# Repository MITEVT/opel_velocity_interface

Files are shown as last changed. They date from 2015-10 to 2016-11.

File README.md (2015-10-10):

# Opel GT Driver Interface Module

MIT EVT's Opel GT Project Driver Interface Module. Acts as an inteface between the user and the electrical system for controlling power distribution and auxiliary peripherals.
	
## Target
NXP LPC11C14 Cortex-M0 Microcontroller

## Description
Takes user input in the form of key switches, level toggles, and button presses to activate main power distribution system and control auxilairy peripherals such as lights.

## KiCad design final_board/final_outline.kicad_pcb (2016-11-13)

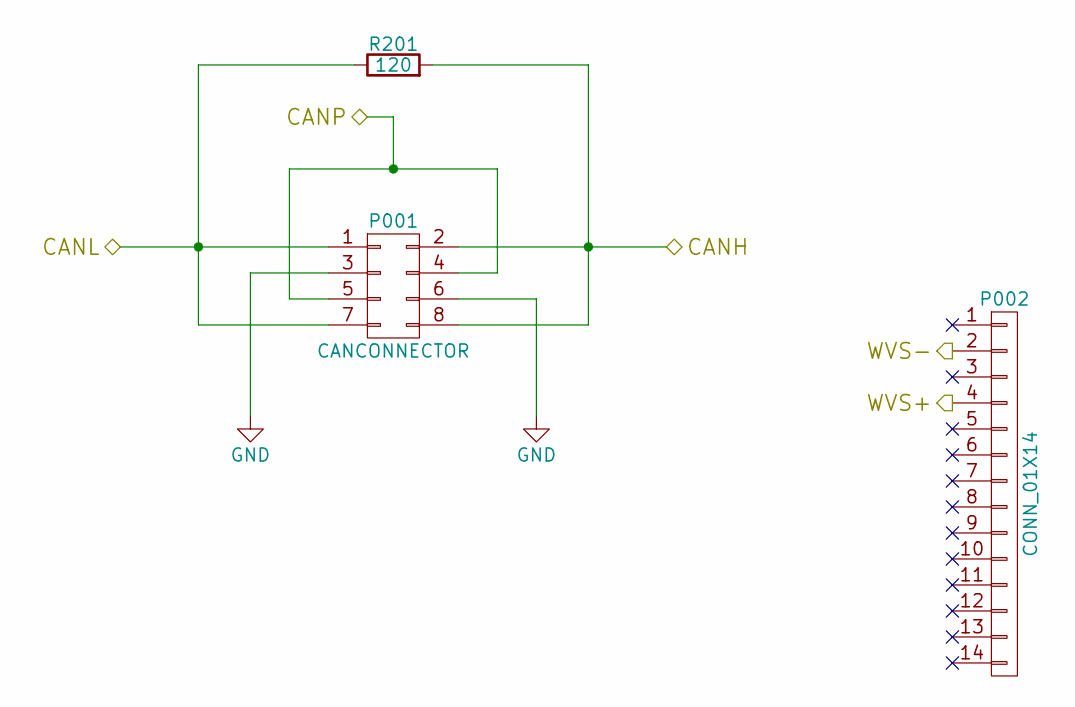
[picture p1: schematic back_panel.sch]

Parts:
P001: CANCONNECTOR; 776280-1
P002: CONN_01X14; 776267-1
R201: 120; R_0603_HandSoldering

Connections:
+12V: P001.4, P001.5; also elsewhere on the board
/BACK_PANEL/CANH: P001.2, P001.8, R201.2; also elsewhere on the board
/BACK_PANEL/CANL: P001.1, P001.7, R201.1; also elsewhere on the board
/BACK_PANEL/WVS+: P002.4; also elsewhere on the board
/BACK_PANEL/WVS-: P002.2; also elsewhere on the board
GND: P001.3, P001.6; also elsewhere on the board

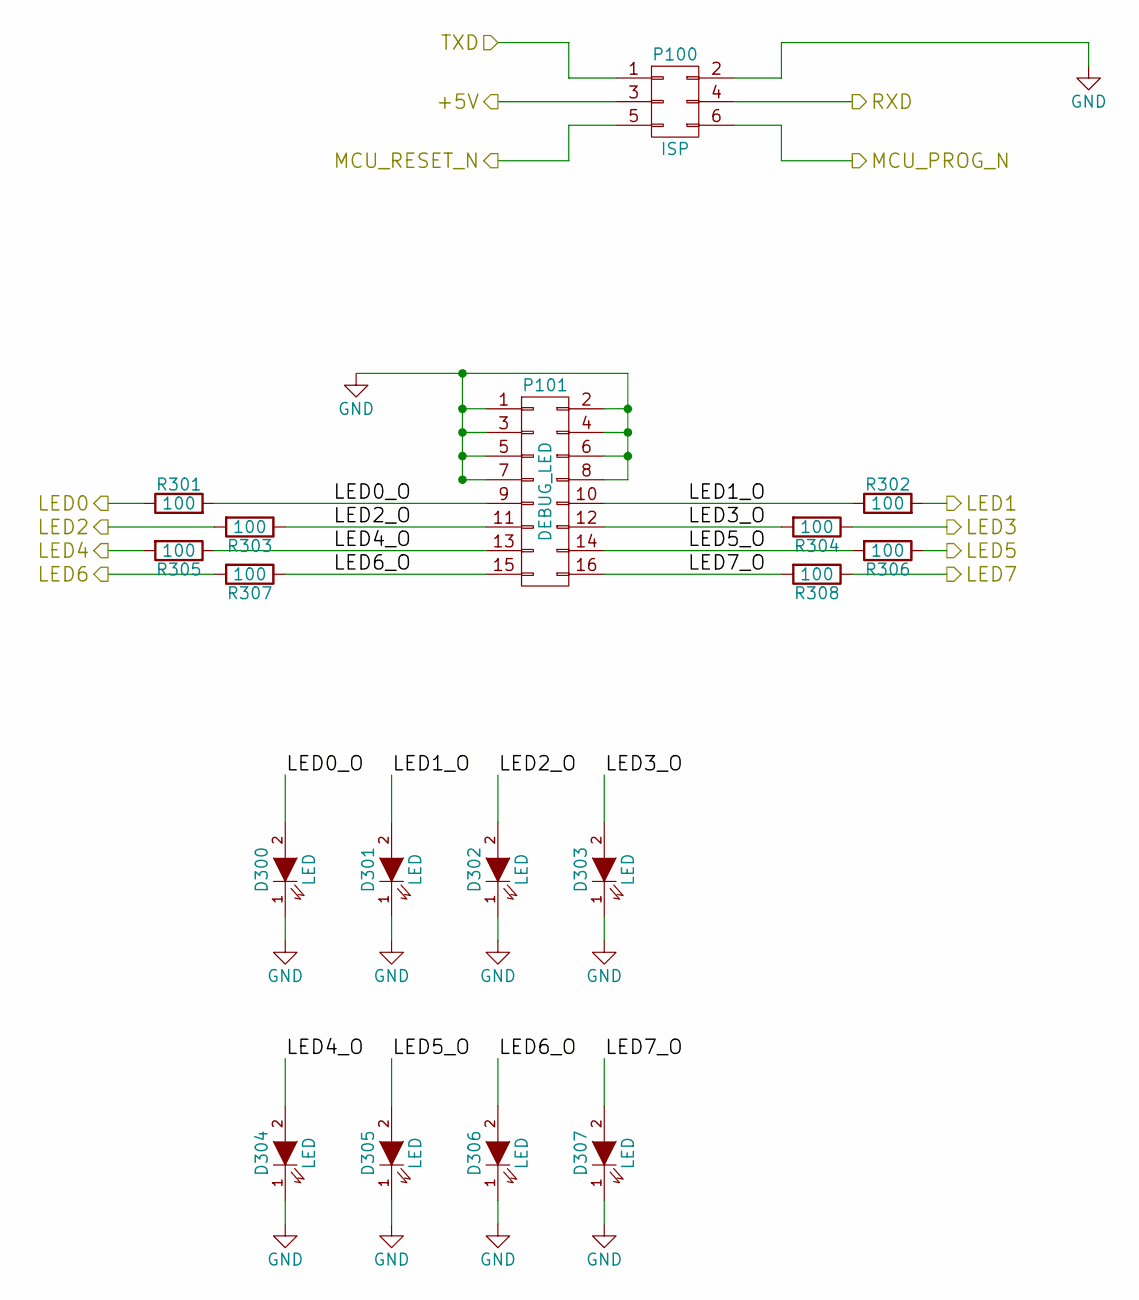
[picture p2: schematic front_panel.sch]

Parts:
D300, D301, D302, D303, D304, D305, D306, D307: LED; LED_0805
P100: ISP; Molex_Microfit3_Header_02x03_Angled_43045-060x
P101: DEBUG_LED; Molex_Microfit3_Header_02x08_Angled_43045-160x
R301, R302, R303, R304, R305, R306, R307, R308: 100; R_0603_HandSoldering

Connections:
+5V: P100.3; also elsewhere on the board
/FRONT_PANEL/LED0: R301.1; also elsewhere on the board
/FRONT_PANEL/LED0_O: D300.2 (A), P101.9, R301.2
/FRONT_PANEL/LED1: R302.2; also elsewhere on the board
/FRONT_PANEL/LED1_O: D301.2 (A), P101.10, R302.1
/FRONT_PANEL/LED2: R303.2; also elsewhere on the board
/FRONT_PANEL/LED2_O: D302.2 (A), P101.11, R303.1
/FRONT_PANEL/LED3: R304.1; also elsewhere on the board
/FRONT_PANEL/LED3_O: D303.2 (A), P101.12, R304.2
/FRONT_PANEL/LED4: R305.2; also elsewhere on the board
/FRONT_PANEL/LED4_O: D304.2 (A), P101.13, R305.1
/FRONT_PANEL/LED5: R306.1; also elsewhere on the board
/FRONT_PANEL/LED5_O: D305.2 (A), P101.14, R306.2
/FRONT_PANEL/LED6: R307.2; also elsewhere on the board
/FRONT_PANEL/LED6_O: D306.2 (A), P101.15, R307.1
/FRONT_PANEL/LED7: R308.1; also elsewhere on the board
/FRONT_PANEL/LED7_O: D307.2 (A), P101.16, R308.2
/FRONT_PANEL/MCU_PROG_N: P100.6; also elsewhere on the board
/FRONT_PANEL/MCU_RESET_N: P100.5; also elsewhere on the board
/FRONT_PANEL/RXD: P100.4; also elsewhere on the board
/FRONT_PANEL/TXD: P100.1; also elsewhere on the board
GND: D300.1 (K), D301.1 (K), D302.1 (K), D303.1 (K), D304.1 (K), D305.1 (K), D306.1 (K), D307.1 (K), P100.2, P101.1, P101.2, P101.3, P101.4, P101.5, P101.6, P101.7, P101.8; also elsewhere on the board

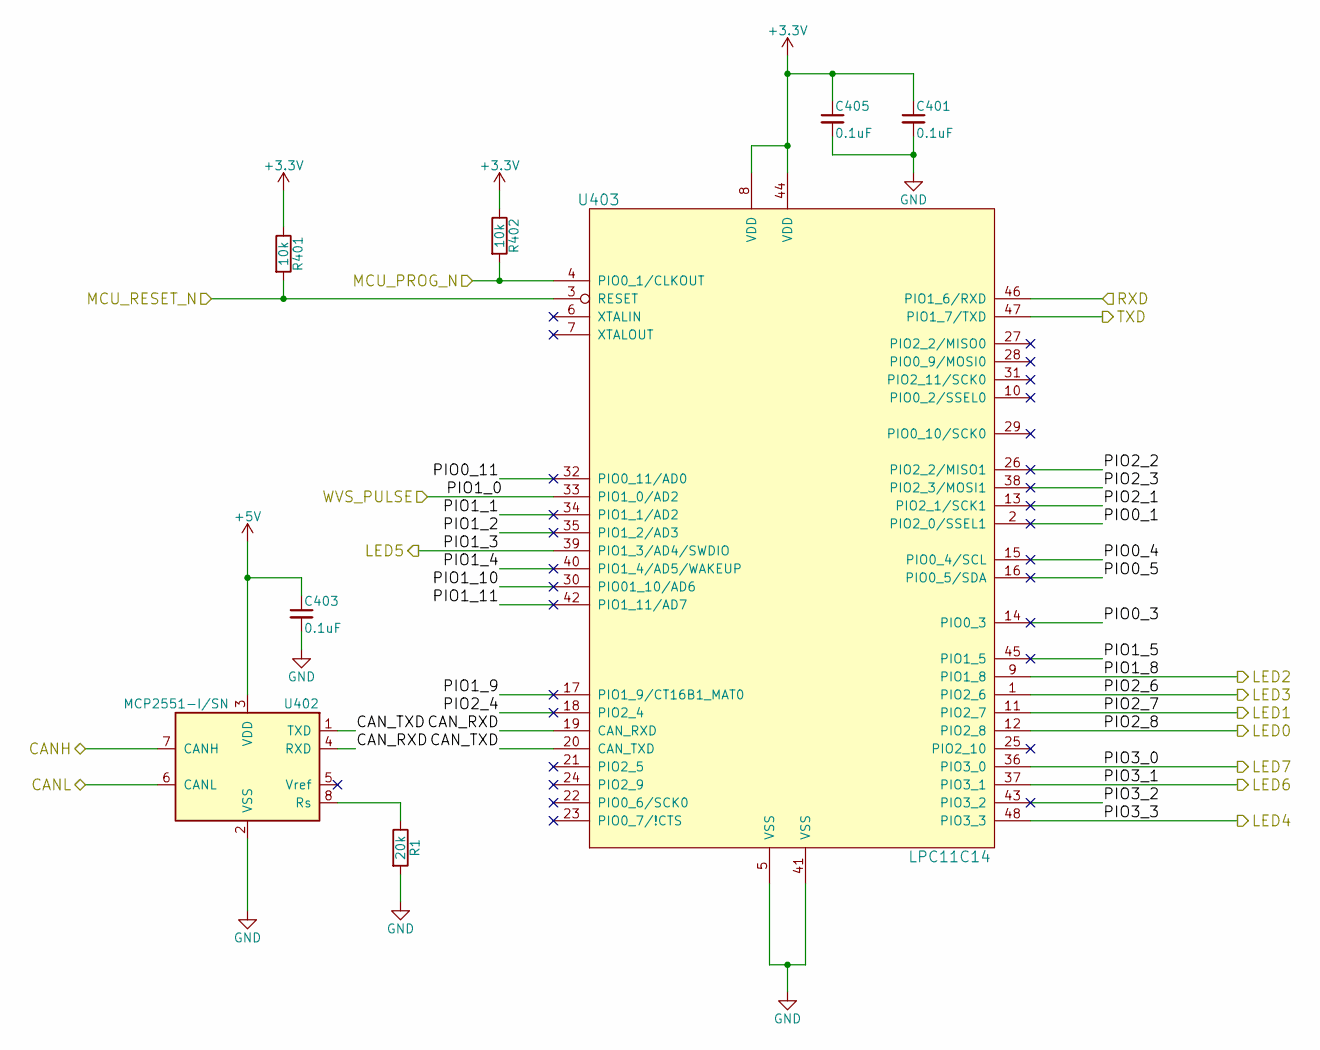
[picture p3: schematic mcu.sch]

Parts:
C401, C403, C405: 0.1uF; C_0603_HandSoldering
R1: 20k; C_0603_HandSoldering
R401, R402: 10k; R_0603_HandSoldering
U402: MCP2551-I/SN; SOIC-8_3.9x4.9mm_Pitch1.27mm
U403: LPC11C14; LQFP-48_7x7mm_Pitch0.5mm

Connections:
+3V3: C401.1, C405.1, R401.1, R402.1, U403.8 (VDD), U403.44 (VDD); also elsewhere on the board
+5V: C403.1, U402.3 (VDD); also elsewhere on the board
/BACK_PANEL/CANH: U402.7 (CANH); also elsewhere on the board
/BACK_PANEL/CANL: U402.6 (CANL); also elsewhere on the board
/FRONT_PANEL/LED0: U403.12 (PIO2_8); also elsewhere on the board
/FRONT_PANEL/LED1: U403.11 (PIO2_7); also elsewhere on the board
/FRONT_PANEL/LED2: U403.9 (PIO1_8); also elsewhere on the board
/FRONT_PANEL/LED3: U403.1 (PIO2_6); also elsewhere on the board
/FRONT_PANEL/LED4: U403.48 (PIO3_3); also elsewhere on the board
/FRONT_PANEL/LED5: U403.39 (PIO1_3/AD4/SWDIO); also elsewhere on the board
/FRONT_PANEL/LED6: U403.37 (PIO3_1); also elsewhere on the board
/FRONT_PANEL/LED7: U403.36 (PIO3_0); also elsewhere on the board
/FRONT_PANEL/MCU_PROG_N: R402.2, U403.4 (PIO0_1/CLKOUT); also elsewhere on the board
/FRONT_PANEL/MCU_RESET_N: R401.2, U403.3 (RESET); also elsewhere on the board
/FRONT_PANEL/RXD: U403.46 (PIO1_6/RXD); also elsewhere on the board
/FRONT_PANEL/TXD: U403.47 (PIO1_7/TXD); also elsewhere on the board
/Micro_Controller/CAN_RXD: U402.4 (RXD), U403.19 (CAN_RXD)
/Micro_Controller/CAN_TXD: U402.1 (TXD), U403.20 (CAN_TXD)
/Micro_Controller/PIO0_1: U403.2 (PIO2_0/SSEL1)
/Micro_Controller/PIO0_3: U403.14 (PIO0_3)
/Micro_Controller/PIO0_4: U403.15 (PIO0_4/SCL)
/Micro_Controller/PIO0_5: U403.16 (PIO0_5/SDA)
/Micro_Controller/PIO0_11: U403.32 (PIO0_11/AD0)
/Micro_Controller/PIO1_1: U403.34 (PIO1_1/AD2)
/Micro_Controller/PIO1_2: U403.35 (PIO1_2/AD3)
/Micro_Controller/PIO1_4: U403.40 (PIO1_4/AD5/WAKEUP)
/Micro_Controller/PIO1_5: U403.45 (PIO1_5)
/Micro_Controller/PIO1_9: U403.17 (PIO1_9/CT16B1_MAT0)
/Micro_Controller/PIO1_10: U403.30 (PIO01_10/AD6)
/Micro_Controller/PIO1_11: U403.42 (PIO1_11/AD7)
/Micro_Controller/PIO2_1: U403.13 (PIO2_1/SCK1)
/Micro_Controller/PIO2_2: U403.26 (PIO2_2/MISO1)
/Micro_Controller/PIO2_3: U403.38 (PIO2_3/MOSI1)
/Micro_Controller/PIO2_4: U403.18 (PIO2_4)
/Micro_Controller/PIO3_2: U403.43 (PIO3_2)
/Micro_Controller/WVS_PULSE: U403.33 (PIO1_0/AD2); also elsewhere on the board
GND: C401.2, C403.2, C405.2, R1.2, U402.2 (VSS), U403.5 (VSS), U403.41 (VSS); also elsewhere on the board
unnamed: R1.1, U402.8 (Rs)

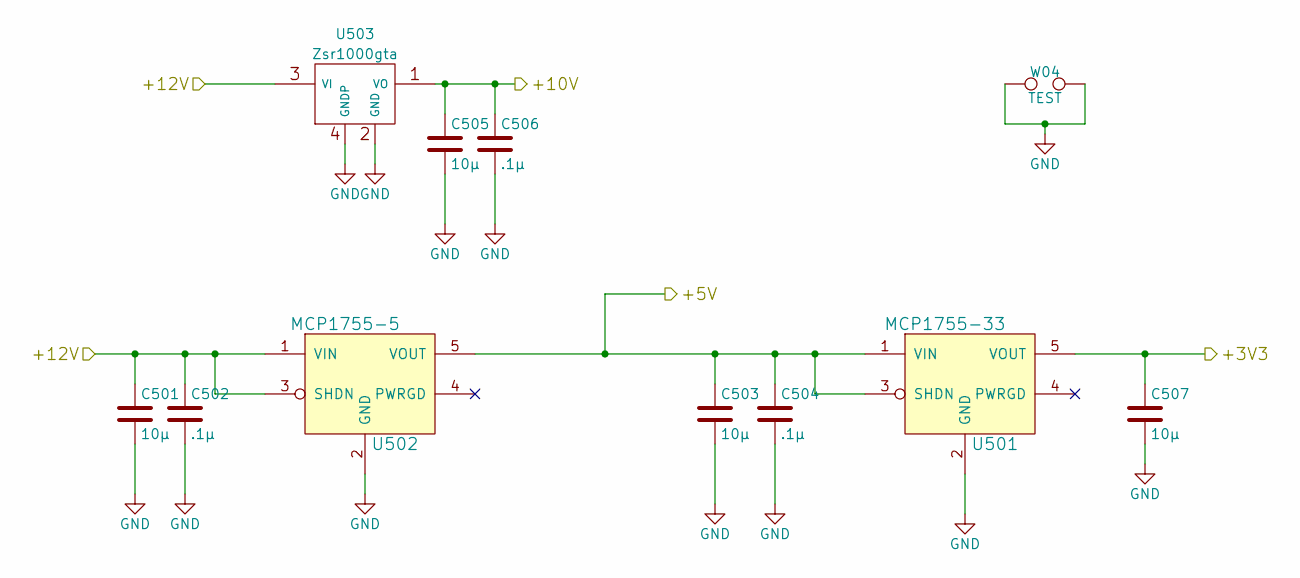
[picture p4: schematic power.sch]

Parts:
C501, C503, C505, C507: 10μ; C_0805_HandSoldering
C502, C504, C506: .1μ; C_0603_HandSoldering
U501: MCP1755-33; SOT-23-5
U502: MCP1755-5; SOT-23-5
U503: Zsr1000gta; SOT-223
W04: TEST; Test_Point_2Pads

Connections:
+3V3: C507.1, U501.5 (VOUT); also elsewhere on the board
+5V: C503.1, C504.1, U501.1 (VIN), U501.3 (SHDN), U502.5 (VOUT); also elsewhere on the board
+12V: C501.1, C502.1, U502.1 (VIN), U502.3 (SHDN), U503.3 (VI); also elsewhere on the board
GND: C501.2, C502.2, C503.2, C504.2, C505.2, C506.2, C507.2, U501.2 (GND), U502.2 (GND), U503.2 (GND), U503.4 (GNDP), W04.1, W04.2; also elsewhere on the board
VCC: C505.1, C506.1, U503.1 (VO); also elsewhere on the board

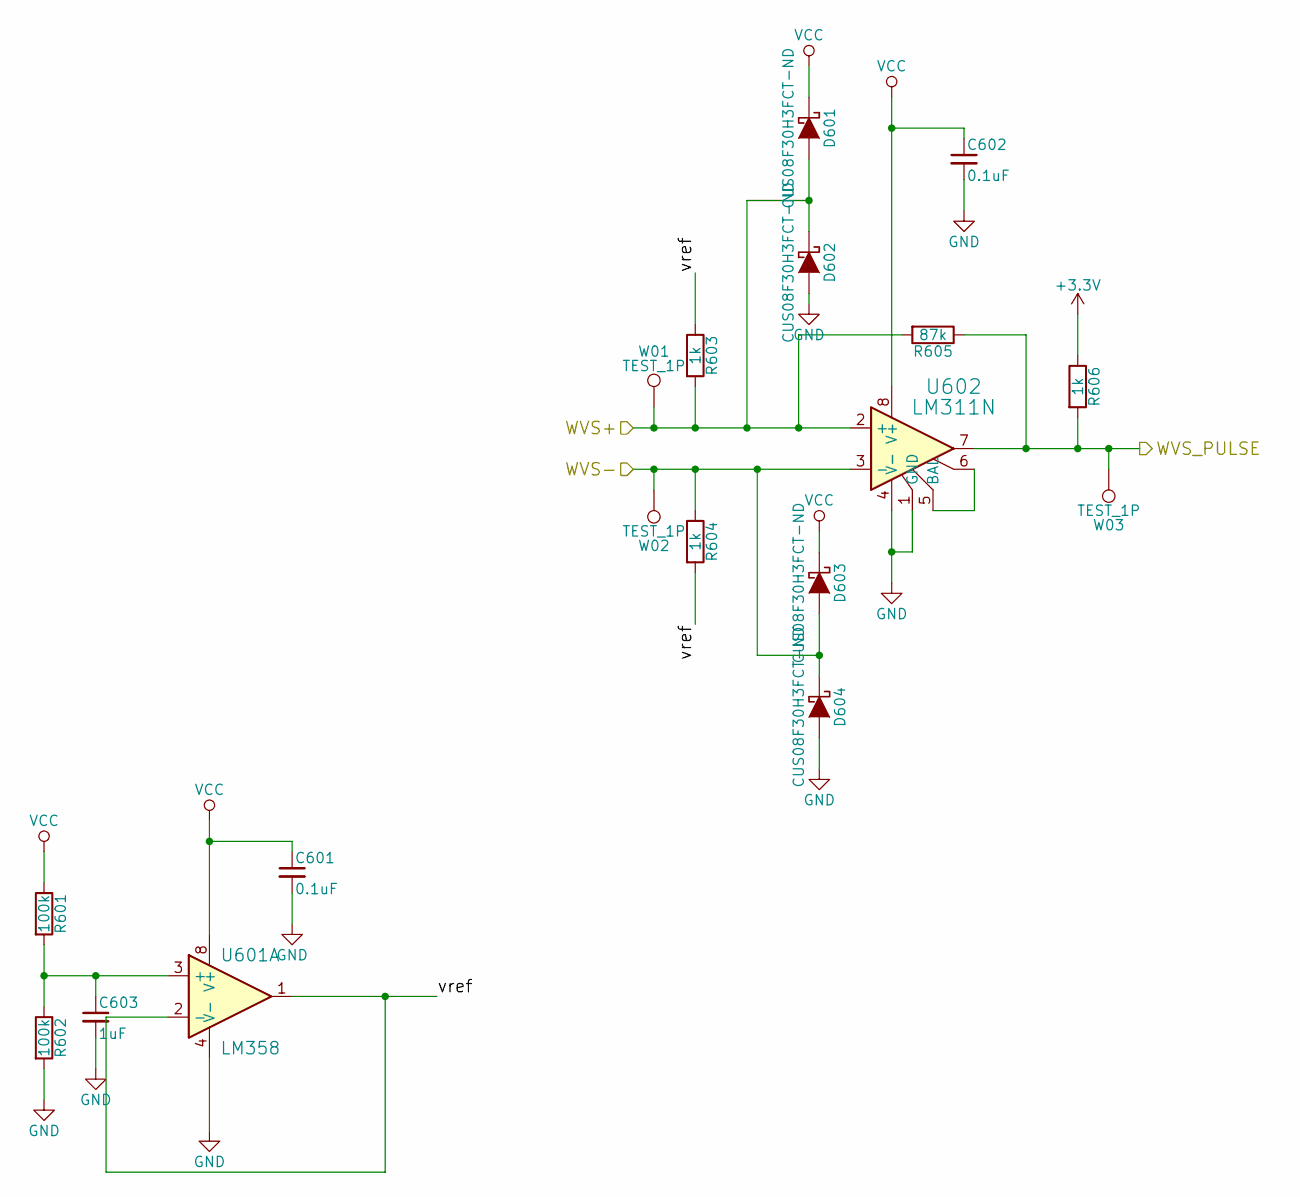
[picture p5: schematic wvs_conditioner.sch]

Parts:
C601, C602: 0.1uF; C_0603_HandSoldering
C603: 1uF; C_0603_HandSoldering
D601, D602, D603, D604: CUS08F30H3FCT-ND; SOD-323
R601, R602: 100k; R_0603_HandSoldering
R603, R604, R606: 1k; R_0603_HandSoldering
R605: 87k; R_0603_HandSoldering
U601: LM358; SOIC-8_3.9x4.9mm_Pitch1.27mm
U602: LM311N; SOIC-8_3.9x4.9mm_Pitch1.27mm
W01, W02, W03: TEST_1P; smd_test_pad

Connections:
+3V3: R606.1; also elsewhere on the board
/BACK_PANEL/WVS+: D601.2 (A), D602.1 (K), R603.2, R605.2, U602.2 (+), W01.1; also elsewhere on the board
/BACK_PANEL/WVS-: D603.2 (A), D604.1 (K), R604.1, U602.3 (-), W02.1; also elsewhere on the board
/Micro_Controller/WVS_PULSE: R605.1, R606.2, U602.7, W03.1; also elsewhere on the board
/WVS_Conditioner/vref: R603.1, R604.2, U601.1, U601.2 (-)
GND: C601.2, C602.2, C603.2, D602.2 (A), D604.2 (A), R602.2, U601.4 (V-), U602.1 (GND), U602.4 (V-); also elsewhere on the board
unnamed: C603.1, R601.2, R602.1, U601.3 (+)
unnamed: U602.5 (BAL), U602.6
VCC: C601.1, C602.1, D601.1 (K), D603.1 (K), R601.1, U601.8 (V+), U602.8 (V+); also elsewhere on the board

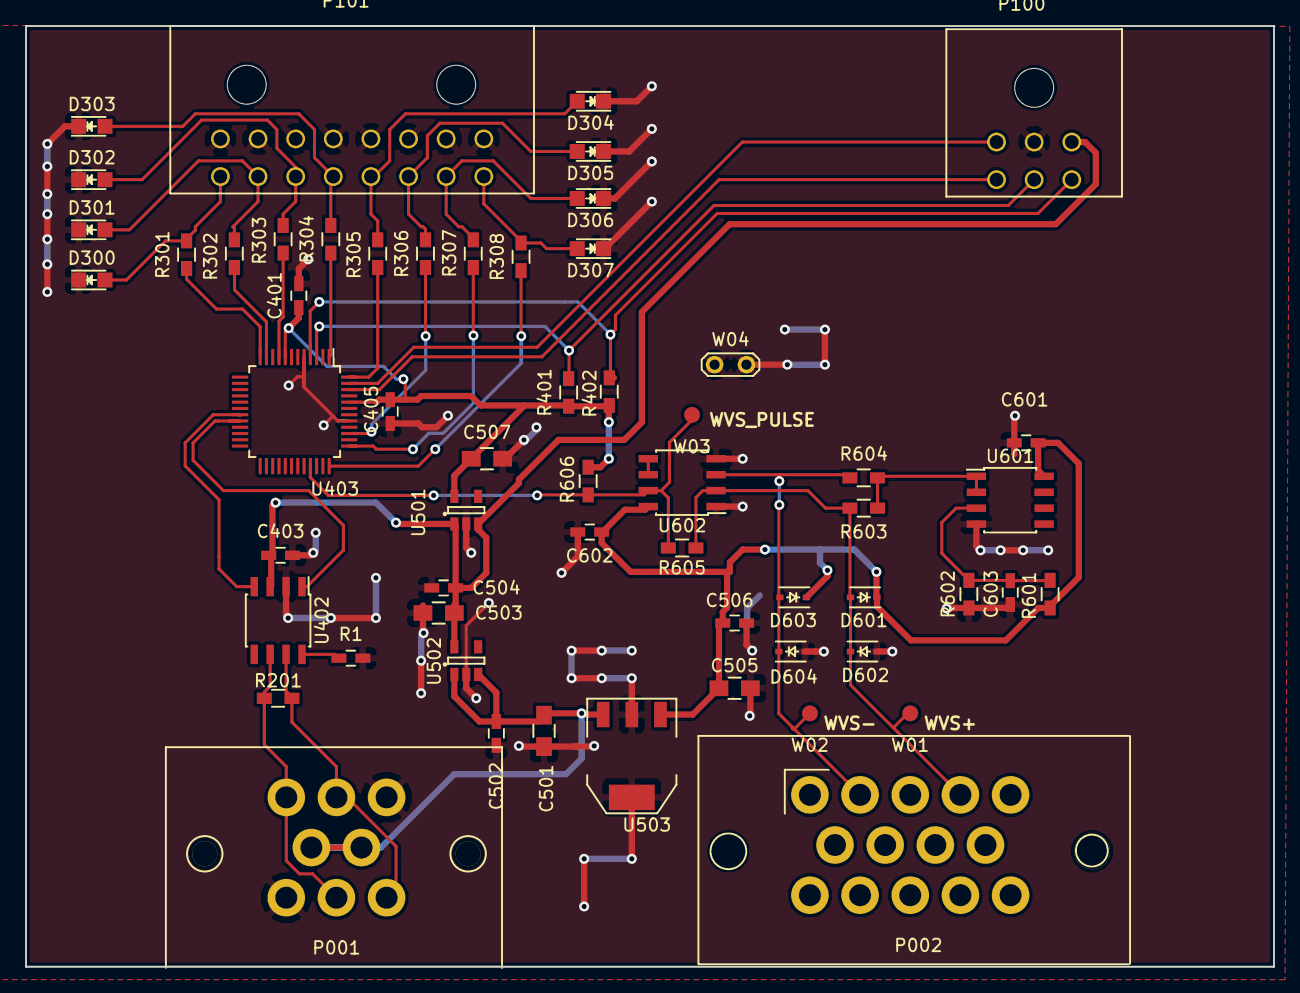
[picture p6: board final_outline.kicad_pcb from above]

Board: 2 copper layers, 99.5 x 75.0 mm, 58 parts (0 on the bottom side), 36 nets.

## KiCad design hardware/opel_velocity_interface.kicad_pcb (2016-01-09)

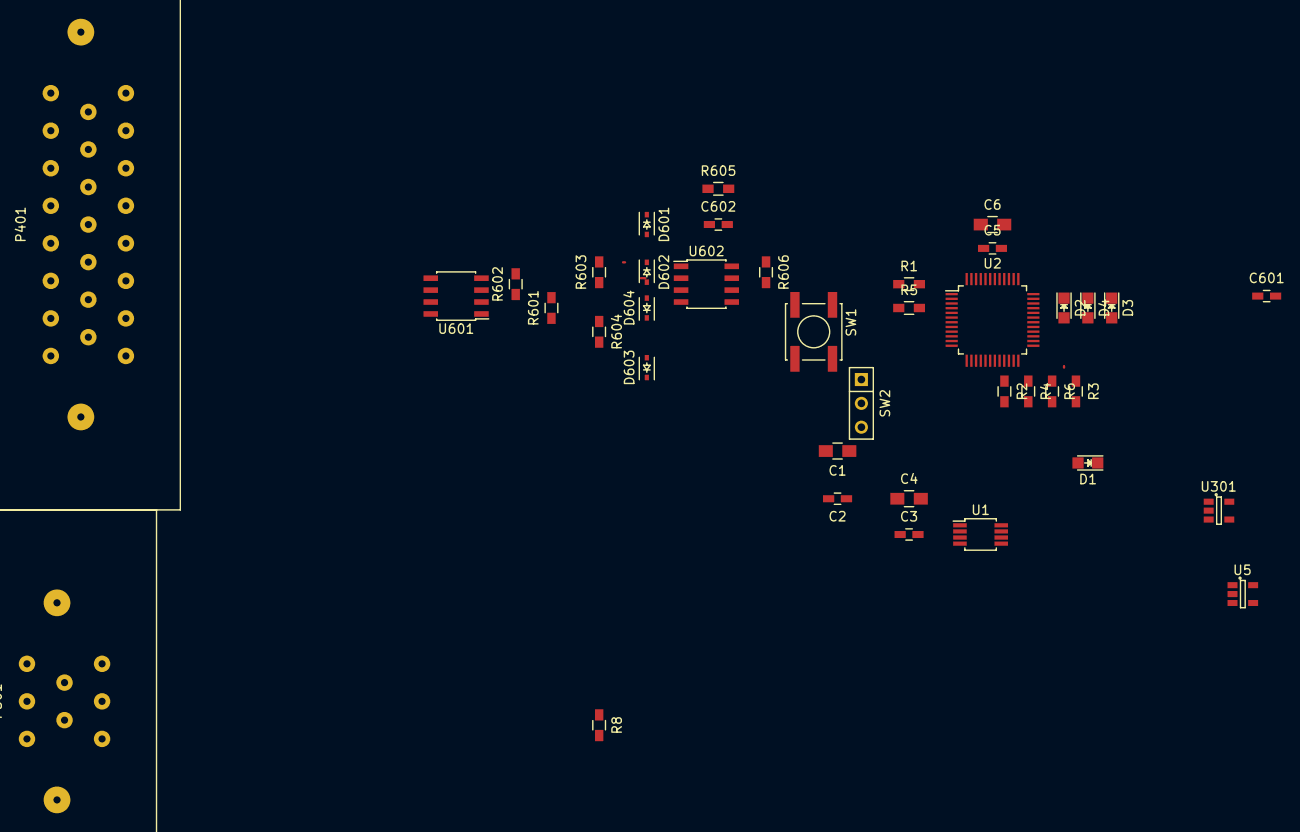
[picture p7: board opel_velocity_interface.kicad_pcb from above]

Board: 2 copper layers, 39 parts (0 on the bottom side), 25 nets.

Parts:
C1, C4: 1uF; C_0805_HandSoldering
C2, C3, C5, C601, C602: 0.1uF; C_0603_HandSoldering
C6: 1=uF; C_0805_HandSoldering
D1, D2, D3, D4: LED; LED-0805
D601, D602, D603, D604: CUS08F30H3FTR-ND; SOD-323
P401: CONN_01X23; 1-776087-2
P501: CONN_01X08; 1-776280-2
R1, R5, R606: 10k; R_0603_HandSoldering
R2, R3, R4, R6: 100; R_0603_HandSoldering
R8: 120; R_0603_HandSoldering
R601, R602, R603, R604: 1k; R_0603_HandSoldering
R605: 87k; R_0603_HandSoldering
SW1: SPST; SW_SPST_EVPBF
SW2: SPST; SW_Micro_SPST
U1: ISO1050; MSOP-8_3x3mm_Pitch0.65mm
U2: LPC11C14; LQFP-48_7x7mm_Pitch0.5mm
U5, U301: MCP1755; SOT-23-5
U601: LM358; SOIC-8_3.9x4.9mm_Pitch1.27mm
U602: LM311N; SOIC-8_3.9x4.9mm_Pitch1.27mm

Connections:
+3V3: C3.1, C4.1, C5.1, C6.1, R1.1, R5.1, R606.1, U1.1, U2.8, U2.44, U5.5
+12V: C601.1, C602.1, D601.1, D603.1, P401.18, R601.1, U5.1, U5.3, U301.1, U301.3, U601.8, U602.8
/Input Connectors/MCU_PROG_N: P401.22, R5.2, SW2.1, U2.4
/Input Connectors/MCU_RESET_N: P401.21, R1.2, SW1.1, U2.3
/Input Connectors/RXD: P401.19, U2.46
/Input Connectors/TXD: P401.20, U2.47
/Input Connectors/WVS+: D601.2, D602.1, R603.2, R605.1, U602.2
/Input Connectors/WVS-: D603.2, D604.1, R604.1, U602.3
/Micro Controller/CAN1H: P501.2, R8.1, U1.7
/Micro Controller/CAN1L: P501.3, R8.2, U1.6
/Micro Controller/CAN1P: C1.1, C2.1, P501.1, U1.8
/Micro Controller/WVS_PULSE: R605.2, R606.2, U2.45, U602.7
/WVS_Conditioner/vref: R603.1, R604.2, U601.1, U601.2
GND: C1.2, C2.2, C3.2, C4.2, C5.2, C6.2, C601.2, C602.2, D1.1, D2.1, D3.1, D4.1, D602.2, D604.2, P401.23, P501.4, R602.2, SW1.2, SW2.2, U1.4, U2.5, U2.41, U5.2, U601.4, U602.4, U602.6
unnamed: D1.2, R2.2
unnamed: D2.2, R3.2
unnamed: D3.2, R4.2
unnamed: D4.2, R6.2
unnamed: R2.1, U2.21
unnamed: R3.1, U2.24
unnamed: R4.1, U2.22
unnamed: R6.1, U2.23
unnamed: R601.2, R602.1, U601.3
unnamed: U1.2, U2.19
unnamed: U1.3, U2.20

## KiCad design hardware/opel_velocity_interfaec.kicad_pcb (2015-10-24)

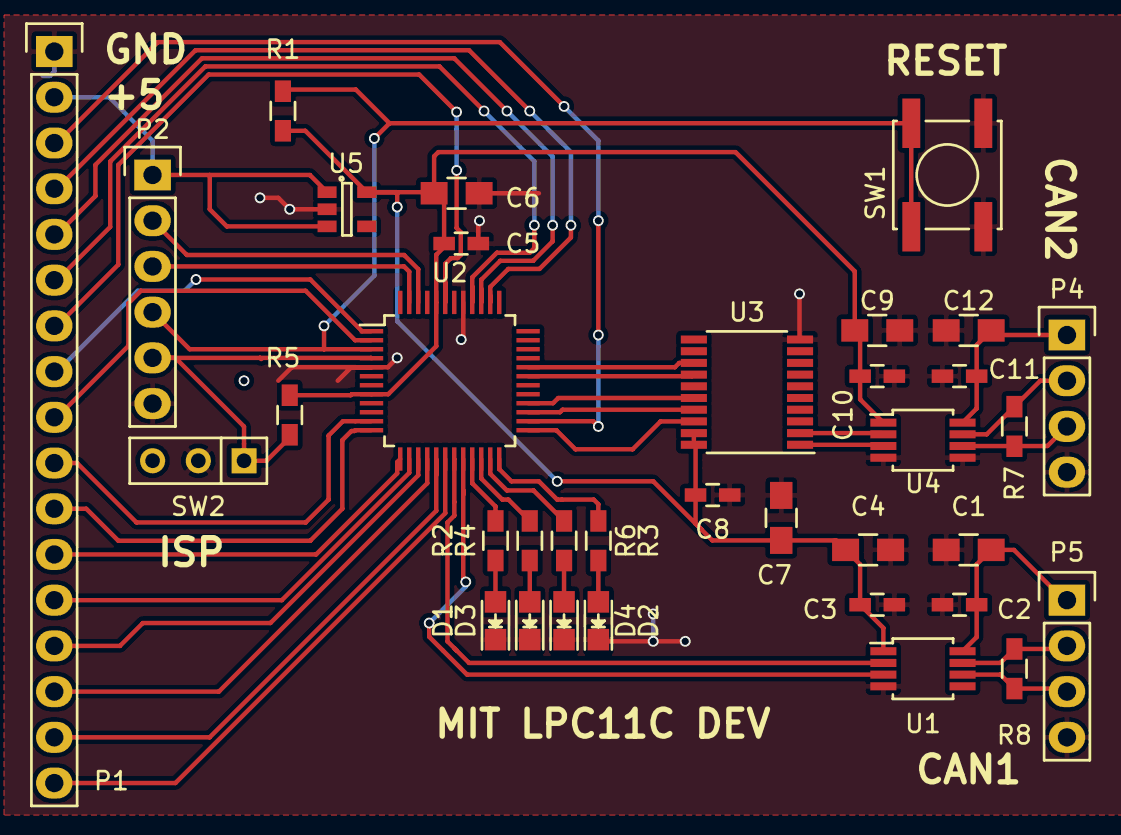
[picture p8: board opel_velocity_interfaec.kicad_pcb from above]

Board: 2 copper layers, 35 parts (0 on the bottom side), 45 nets.

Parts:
C1, C4: 10uF; C_0805_HandSoldering
C2, C3, C5, C8, C10, C11: 0.1uF; C_0603_HandSoldering
C6: 1=uF; C_0805_HandSoldering
C7, C9, C12: 1uF; C_0805_HandSoldering
D1, D2, D3, D4: LED; LED-0805
P1: CONN_01X17; Pin_Header_Straight_1x17
P2: CONN_01X06; Pin_Header_Straight_1x06
P4, P5: CONN_01X04; Pin_Header_Straight_1x04
R1, R5: 10k; R_0603_HandSoldering
R2, R3, R4, R6: 100; R_0603_HandSoldering
R7, R8: 120; R_0603_HandSoldering
SW1: SPST; SW_SPST_EVPBF
SW2: SPST; SW_Micro_SPST
U1, U4: ISO1050; MSOP-8_3x3mm_Pitch0.65mm
U2: LPC11C14; LQFP-48_7x7mm_Pitch0.5mm
U3: MCP2515_TSSOP; TSSOP-20_4.4x6.5mm_Pitch0.65mm
U5: MCP1755; SOT-23-5

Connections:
+3V3: C3.1, C4.1, C5.1, C6.1, C7.1, C8.1, C9.1, C10.1, R1.1, R5.1, U1.1, U2.8, U2.44, U3.19, U3.20, U4.1, U5.5
+5V: P1.2, P2.1, U5.1, U5.3
/Input Connectors/MCU_PROG_N: P2.5, R5.2, SW2.1, U2.4
/Input Connectors/MCU_RESET_N: P2.4, R1.2, SW1.1, U2.3
/Input Connectors/RXD: P2.2, U2.46
/Input Connectors/TXD: P2.3, U2.47
/Micro Controller/CAN1H: P5.2, R8.1, U1.7
/Micro Controller/CAN1L: P5.3, R8.2, U1.6
/Micro Controller/CAN1P: C1.1, C2.1, P5.1, U1.8
/Micro Controller/CAN2H: P4.2, R7.1, U4.7
/Micro Controller/CAN2L: P4.3, R7.2, U4.6
/Micro Controller/CAN2P: C11.1, C12.1, P4.1, U4.8
/Micro Controller/PIO0_1: P1.9, U2.2
/Micro Controller/PIO0_3: P1.13, U2.14
/Micro Controller/PIO0_4: P1.14, U2.15
/Micro Controller/PIO0_5: P1.15, U2.16
/Micro Controller/PIO0_11: U2.32, U3.13
/Micro Controller/PIO1_3: P1.5, U2.39
/Micro Controller/PIO1_4: P1.6, U2.40
/Micro Controller/PIO1_9: P1.16, U2.17
/Micro Controller/PIO2_1: P1.12, U2.13
/Micro Controller/PIO2_2: P1.3, U2.26
/Micro Controller/PIO2_3: P1.4, U2.38
/Micro Controller/PIO2_4: P1.17, U2.18
/Micro Controller/PIO2_6: P1.8, U2.1
/Micro Controller/PIO2_7: P1.10, U2.11
/Micro Controller/PIO2_8: P1.11, U2.12
/Micro Controller/PIO3_2: P1.7, U2.43
GND: C1.2, C2.2, C3.2, C4.2, C5.2, C6.2, C7.2, C8.2, C9.2, C10.2, C11.2, C12.2, D1.1, D2.1, D3.1, D4.1, P1.1, P2.6, P4.4, P5.4, SW1.2, SW2.2, U1.4, U2.5, U2.41, U3.10, U4.4, U4.5, U5.2
unnamed: D1.2, R2.2
unnamed: D2.2, R3.2
unnamed: D3.2, R4.2
unnamed: D4.2, R6.2
unnamed: R2.1, U2.21
unnamed: R3.1, U2.24
unnamed: R4.1, U2.22
unnamed: R6.1, U2.23
unnamed: U1.2, U2.19
unnamed: U1.3, U2.20
unnamed: U2.25, U3.18
unnamed: U2.27, U3.17
unnamed: U2.28, U3.16
unnamed: U2.31, U3.14
unnamed: U3.1, U4.3
unnamed: U3.2, U4.2

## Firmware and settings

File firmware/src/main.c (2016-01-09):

#include "board.h"
#include <string.h>

// -------------------------------------------------------------
// Macro Definitions

#define CCAN_BAUD_RATE 500000 					// Desired CAN Baud Rate
#define UART_BAUD_RATE 9600 					// Desired UART Baud Rate
#define GMB_EDGES_PER_ROTATION 49	 		        // Clock edges per wheel rotation for GBM wheel bearing sensor

#define BUFFER_SIZE 8

// -------------------------------------------------------------
// Static Variable Declaration

extern volatile uint32_t msTicks;

// Variables for the wheel velocity tracking
static char rpm_str[23];		// Used for composing UART messages
volatile static uint32_t rpm_ticks;	// The current running average of time
volatile static uint32_t rpm_count;	// Number of samples taken since the last output
volatile static uint16_t curr_rpm;	// Current RPM measurement

static CCAN_MSG_OBJ_T msg_obj; 			// Message Object data structure for manipulating CAN messages
static RINGBUFF_T can_rx_buffer; 		// Ring Buffer for storing received CAN messages
static CCAN_MSG_OBJ_T _rx_buffer[BUFFER_SIZE]; 	// Underlying array used in ring buffer

static char str[100];				// Used for composing UART messages
static uint8_t uart_rx_buffer[BUFFER_SIZE]; 	// UART received message buffer

static bool can_error_flag;
static uint32_t can_error_info;

static uint32_t lastPrint;

// -------------------------------------------------------------
// Helper Functions

/**
 * Delay the processor for a given number of milliseconds
 * @param ms Number of milliseconds to delay
 */
void _delay(uint32_t ms) {
	uint32_t curTicks = msTicks;
	while ((msTicks - curTicks) < ms);
}

// -------------------------------------------------------------
// CAN Driver Callback Functions

/*	CAN receive callback */
/*	Function is executed by the Callback handler after
    a CAN message has been received */
void CAN_rx(uint8_t msg_obj_num) {
	/* Determine which CAN message has been received */
	msg_obj.msgobj = msg_obj_num;
	/* Now load up the msg_obj structure with the CAN message */
	LPC_CCAN_API->can_receive(&msg_obj);
	if (msg_obj_num == 1) {
		RingBuffer_Insert(&can_rx_buffer, &msg_obj);
	}
}

/*	CAN transmit callback */
/*	Function is executed by the Callback handler after
    a CAN message has been transmitted */
void CAN_tx(uint8_t msg_obj_num) {
	msg_obj_num = msg_obj_num;
}

/*	CAN error callback */
/*	Function is executed by the Callback handler after
    an error has occurred on the CAN bus */
void CAN_error(uint32_t error_info) {
	can_error_info = error_info;
	can_error_flag = true;
}

// -------------------------------------------------------------
// Interrupt Service Routines

void TIMER32_0_IRQHandler(void){
	Board_Timer0_Reset_Clear();
	rpm_ticks = (rpm_ticks*rpm_count+Board_Timer0_ReadCapture())/(1+rpm_count);	// Continue the running average 
	rpm_count++;    								// Increase the count to allow the running average to be properly computed
}
// -------------------------------------------------------------
// Main Program Loop

int main(void)
{

	//---------------
	// Initialize SysTick Timer to generate millisecond count
	if (Board_SysTick_Init()) {
		// Unrecoverable Error. Hang.
		while(1);
	}

	//---------------
	// Initialize GPIO and LED as output
	Board_LEDs_Init();
	Board_LED_On(LED0);

	//---------------
	// Initialize UART Communication
	Board_UART_Init(UART_BAUD_RATE);
	Board_UART_Println("Started up");

	//---------------
	// Initialize CAN  and CAN Ring Buffer

	RingBuffer_Init(&can_rx_buffer, _rx_buffer, sizeof(CCAN_MSG_OBJ_T), BUFFER_SIZE);
	RingBuffer_Flush(&can_rx_buffer);
	Board_CAN_Init(CCAN_BAUD_RATE, CAN_rx, CAN_tx, CAN_error);

	rpm_count = 0;

	Board_Setup_Timers();

	// For your convenience.
	// typedef struct CCAN_MSG_OBJ {
	// 	uint32_t  mode_id;
	// 	uint32_t  mask;
	// 	uint8_t   data[8];
	// 	uint8_t   dlc;
	// 	uint8_t   msgobj;
	// } CCAN_MSG_OBJ_T;

	/* [Tutorial] How do filters work?

		Incoming ID & Mask == Mode_ID for msgobj to accept message

		Incoming ID : 0xabc
		Mask: 		  0xF0F &
		            -----------
		              0xa0c

		mode_id == 0xa0c for msgobj to accept message

	*/

	msg_obj.msgobj = 1;
	msg_obj.mode_id = 0x703;
	msg_obj.mask = 0x7FF;
	LPC_CCAN_API->config_rxmsgobj(&msg_obj);

	/* [Tutorial] How do I send a CAN Message?

		There are 32 Message Objects in the CAN Peripherals Message RAM.
		We need to pick one that isn't setup for receiving messages and use it to send.

		For this exmaple we'll pick 31

		msg_obj.msgobj = 31;
		msg_obj.mode_id = 0x600; 		// CAN ID of Message to Send
		msg_obj.dlc = 8; 				// Byte length of CAN Message
		msg_obj.data[0] = 0xAA; 		// Fill your bytes here
		msg_obj.data[1] = ..;
		..
		msg_obj.data[7] = 0xBB:

		Now its time to send
		LPC_CCAN_API->can_transmit(&msg_obj);

	*/

	can_error_flag = false;
	can_error_info = 0;

	lastPrint = msTicks;

	while (1) {
        
		if (can_error_flag) {
			can_error_flag = false;
			Board_UART_Print("CAN Error: 0b");
			itoa(can_error_info, str, 2);
			Board_UART_Println(str);
		}

		if(lastPrint+200<msTicks){							// 5 times per second
     			curr_rpm = 60 * SystemCoreClock/rpm_ticks/GMB_EDGES_PER_ROTATION;	// Convert from ticks to rpm
			itoa(curr_rpm, rpm_str, 10); 						// Convert to string
			rpm_ticks = 0;								// Set the average time back to 0
			rpm_count = 0;								// Set the count for the average back to 0

			Board_UART_Print("Sending wheel velocity CAN message with ID: 0x703 Data: ");	// Print a UART Message with the current rpm
			Board_UART_Println(rpm_str);

			msg_obj.mode_id = 0x703;		//Setup the CAN message
			msg_obj.msgobj = 2;
			msg_obj.dlc = 2;
			msg_obj.data_16[0] = curr_rpm;
			LPC_CCAN_API->can_transmit(&msg_obj);	//Transmit to the Vehicle
			lastPrint = msTicks;							// Reset the .2 second timer
		}

	}
}

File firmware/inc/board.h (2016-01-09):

#ifndef __BOARD_H_
#define __BOARD_H_

#include "chip.h"
#include "util.h"
#include <string.h>

// -------------------------------------------------------------
// Global Variables

extern const uint32_t OscRateIn; 
volatile uint32_t msTicks; 						// Running count of milliseconds since start

// -------------------------------------------------------------
// Configuration Macros


// -------------------------------------------------------------
// Pin Descriptions

#define LED0_PORT 2
#define LED0_PIN 10

#define LED1_PORT 0
#define LED1_PIN 6

#define UART_RX_PORT 1
#define UART_RX_PIN 6
#define UART_RX_IOCON IOCON_PIO1_6

#define UART_TX_PORT 1
#define UART_TX_PIN 7
#define UART_TX_IOCON IOCON_PIO1_7

// -------------------------------------------------------------
// Computed Macros

#define LED0 LED0_PORT, LED0_PIN
#define LED1 LED1_PORT, LED1_PIN

#define UART_RX UART_RX_PORT, UART_RX_PIN
#define UART_TX UART_TX_PORT, UART_TX_PIN

#define Board_LED_On(led) Chip_GPIO_SetPinState(LPC_GPIO, led, true)
#define Board_LED_Off(led) Chip_GPIO_SetPinState(LPC_GPIO, led, false)
 
// -------------------------------------------------------------
// Board Level Function Prototypes

int8_t Board_SysTick_Init(void);

void Board_LEDs_Init(void);

void Board_UART_Init(uint32_t baudrate);

/**
 * Transmit the given string through the UART peripheral (blocking)
 * 
 * @param str pointer to string to transmit
 * @note	This function will send or place all bytes into the transmit
 *			FIFO. This function will block until the last bytes are in the FIFO.
 */
void Board_UART_Print(const char *str);

/**
 * Transmit a string through the UART peripheral and append a newline and a linefeed character (blocking)
 * 
 * @param str pointer to string to transmit
 * @note	This function will send or place all bytes into the transmit
 *			FIFO. This function will block until the last bytes are in the FIFO.
 */
void Board_UART_Println(const char *str);

/**
 * Transmit a string containing a number through the UART peripheral (blocking)
 * 
 * @param num number to print
 * @param base number base
 * @param crlf append carraige return and line feed
 */
void Board_UART_PrintNum(const int num, uint8_t base, bool crlf);

/**
 * Transmit a byte array through the UART peripheral (blocking)
 * 
 * @param	data		: Pointer to data to transmit
 * @param	num_bytes	: Number of bytes to transmit
 * @note	This function will send or place all bytes into the transmit
 *			FIFO. This function will block until the last bytes are in the FIFO.
 */
void Board_UART_SendBlocking(const void *data, uint8_t num_bytes);

/**
 * Read data through the UART peripheral (non-blocking)
 * 
 * @param	data		: Pointer to bytes array to fill
 * @param	num_bytes	: Size of the passed data array
 * @return	The actual number of bytes read
 * @note	This function reads data from the receive FIFO until either
 *			all the data has been read or the passed buffer is completely full.
 *			This function will not block. This function ignores errors.
 */
int8_t Board_UART_Read(void *data, uint8_t num_bytes);

void Board_CAN_Init(uint32_t baudrate, void (*rx_callback)(uint8_t), void (*tx_callback)(uint8_t), void (*error_callback)(uint32_t));

/*
 * Reset 32 bit Timer 0 and clear interrupts
 *
 */
void Board_Timer0_Reset_Clear(void);

/*
 * Read the capture register of 32 bit Timer 0
 *
 * @return	The value of capture register 0 of 32 bit Timer 0
 *
*/

uint32_t Board_Timer0_ReadCapture(void);

/*
 * Setup the Timer
 *
*/
void Board_Setup_Timers(void);

#endif

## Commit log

2015-10-24 First draft of WVS schematic
    [inputConnectors.sch, mcu.sch, opel_driver_interface.kicad_pcb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]
2015-10-25 wheel velocity
2015-10-31 Works for transmitting, some formatting corrections
    [main.c]
2015-10-31 Back to only one sensor
2016-01-09 Fixed some formatting and made slight readability changes
    [main.c]
2016-01-09 velocity sensor added
    [inputConnectors.sch, mcu.sch, opel_velocity_interface.sch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]
2016-01-09 wheel velocity sensor circuit added
    [back_panel.sch, final_outline.kicad_pcb, final_outline.sch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]
2016-01-09 Changed CAN Chip, added capacitors, added reference
    [mcu.sch, power.sch]
2016-01-09 Final changes to board
    [back_panel.sch, final_outline.kicad_pcb, final_outline.sch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]
2016-01-13 Fixed some routing
    [back_panel.sch, final_outline.sch, front_panel.sch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]
2016-01-13 The ISP is no longer providing 12 volts
    [final_outline.kicad_pcb]
2016-01-13 Removed useless trace
    [final_outline.kicad_pcb]
2016-01-13 Fixed planes
    [final_outline.kicad_pcb]
2016-01-13 Panelized version
    [panelized.kicad_pcb]
2016-01-14 Resistor values changed from 1k to 100k
    [final_outline.kicad_pcb, wvs_conditioner.sch]
2016-09-17 Added ground via
    [final_outline.kicad_pcb]
2016-11-13 Updated PCB by replacing old parts, fixing voltage regulator, adding test points, and general improvements
    [back_panel.sch, final_outline.kicad_pcb, front_panel.sch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]
